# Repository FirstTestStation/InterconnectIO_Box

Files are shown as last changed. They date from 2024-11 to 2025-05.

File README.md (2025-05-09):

# FIRST STATION TEST InterconnectIO_BOX 500-1000-010

## Project Overview
This project involves the assembly of a custom **InterconnectIO_BOX** designed to be part of the **First TestStation** project ([FTS](https://FirstTestStation.github.io/FTS_Website/)). The primary goal of the InterconnectIO_BOX is to provide an interface between instruments and the Unit Under Test (U.U.T).

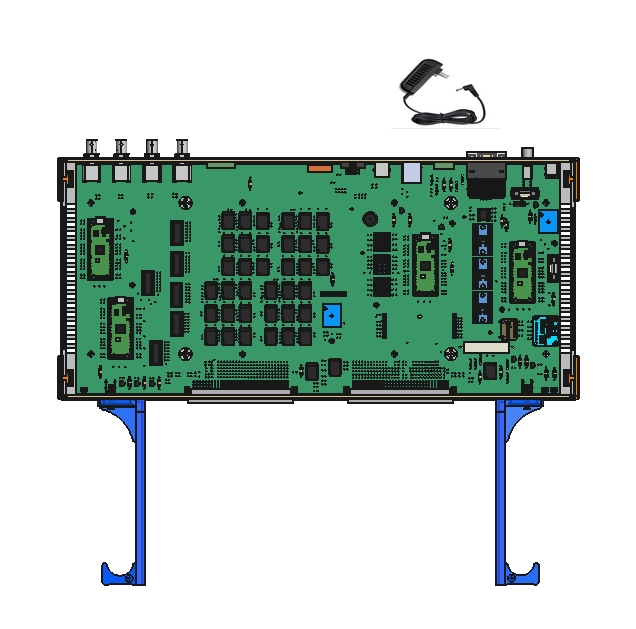
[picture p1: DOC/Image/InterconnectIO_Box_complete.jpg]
Box


### Design Tools
- [Freecad 0.20.2 ](https://www.freecad.org/) - Free software application used to design rail guides and assemble the box.
- [Inkscape 1.1.2 ](https://inkscape.org/) - Free software application used to design front and back panel.
- [LibreOffice](https://www.libreoffice.org/download/download-libreoffice/) - Free Software application used to create assembly instructions and the Bill of Materials (BOM).
- [PicPick](https://picpick.app/en/) - Free application to capture and document image.

### Features

- **Stand-alone Operation**: The box is capable of functioning independently, without requiring external instruments or additional equipment.
- **Rackmount Capability**: Designed to be easily mounted in a standard rack chassis, providing flexibility for different setups.
- **Cost-Effective**: Built using affordable, readily available components, ensuring low production costs.

## Assembly Instructions
   Follow the document [Assembly_Instructions](pdf/InterconnectIO_Box_Assembly_Instruction_520-1000.pdf) to complete the assembly of the board.

## Design Files
- [Left Card Guide stl File](Drawing/Left_guide_drawing_515-1000.stl) – STL file for the left rail, to be used with a 3D printer.
- [Right Card Guide stl File](Drawing/Right_guide_drawing_515-1010.stl) – STL file for the right rail, to be used with a 3D printer.
- [Front panel drawing](Drawing/Panel_Front_drawing_512-1000.svg) – SVG file for the front panel, to be used with a laser cutter.
- [Back panel drawing](Drawing/Panel_Back_drawing_512-1010.svg) – SVG file for the back panel, to be used with a laser cutter.
- [Bill of Materials(BOM)](pdf/BOM_InterconnectIO_Box_510-1000.pdf) – List of components required to complete the assembly.
- [Freecad Folder](Freecad/) – Freecad Original design files.

## Verification
The **InterconnectIO Box** is equipped with multiple built-in features designed to facilitate the comprehensive verification of hardware functionality. It supports **SCPI commands**, allowing for internal testing and diagnostics. The hardware has been engineered specifically to aid in the validation of board functionality, ensuring thorough and efficient testing.

For detailed testing procedures, please refer to the [Test_Instructions](pdf/InterconnectIO_Box_Test_Instruction_520-1010.pdf) document to complete the verification of the InterconnectIO Box.

> **Note:** Verification can also be performed using the OpenTAP TestPlan software available in the GitHub repository:  
> [OpenTAP Selftest Sequence](https://github.com/FirstTestStation/FTS_OpenTAP_Selftest_Sequence)

## License

This project is licensed under the terms of the [CERN Open Hardware License Version 2 - Weakly Reciprocal (CERN-OHL-W 2.0)](https://ohwr.org/cern_ohl_w_v2.txt).

See the [LICENSE](./LICENSE) file in this repository for more details.

---

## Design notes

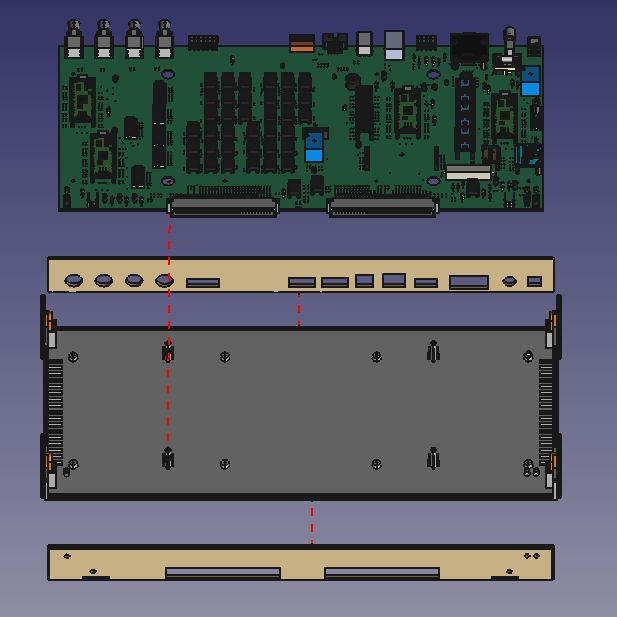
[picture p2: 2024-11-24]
DOC/Image/pcb_mount.jpg

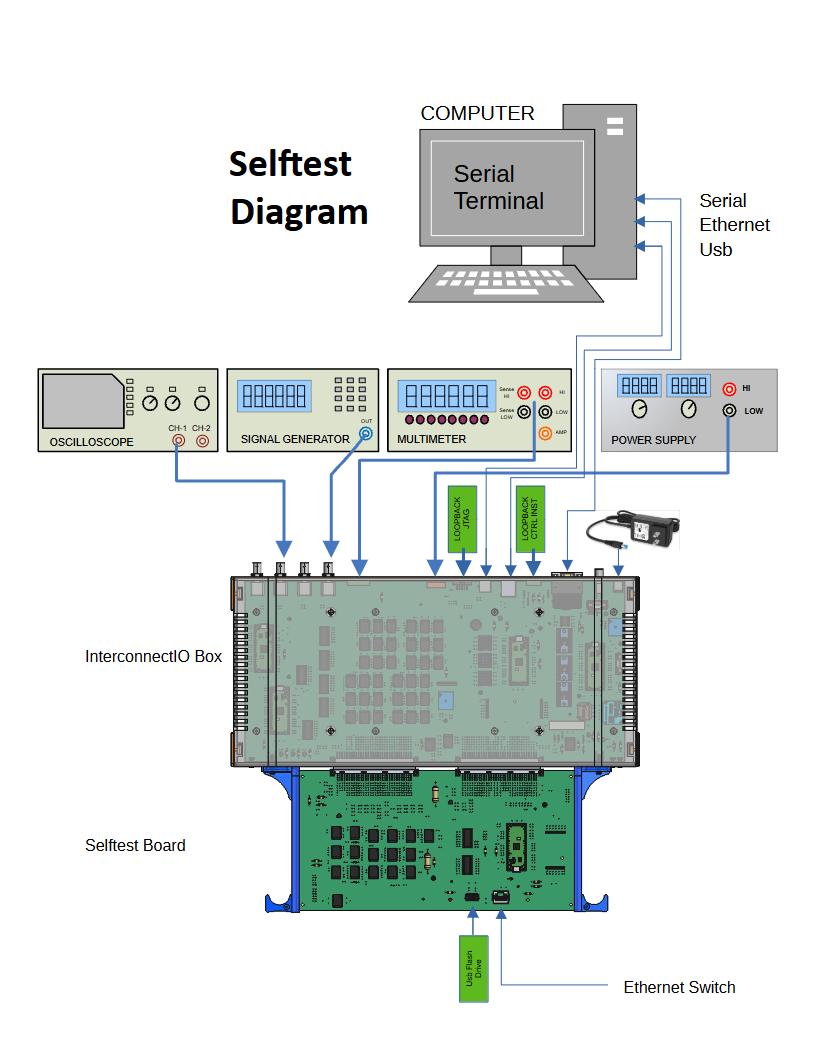
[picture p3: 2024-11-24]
DOC/Image/Selftest_diagram.jpg

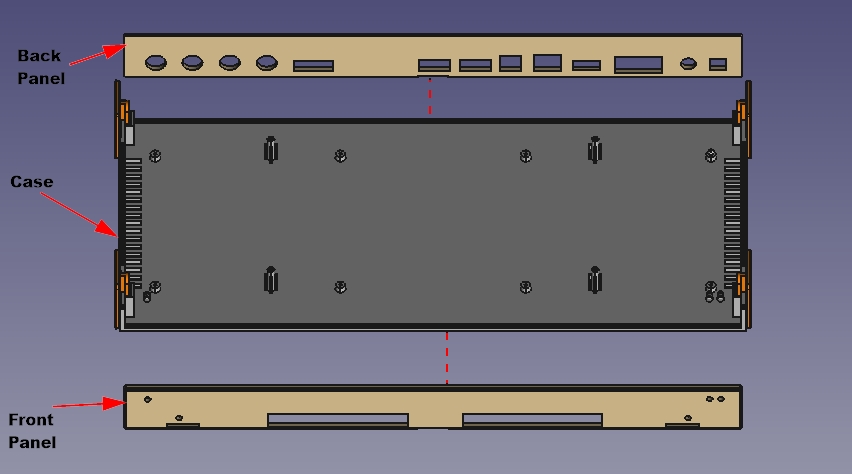
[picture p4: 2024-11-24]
DOC/Image/box_panel_doc.jpg

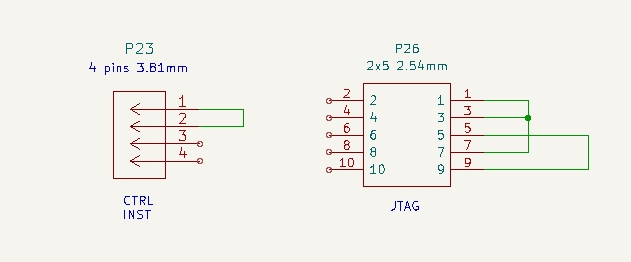
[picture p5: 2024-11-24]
DOC/Image/loopback_connector.jpg

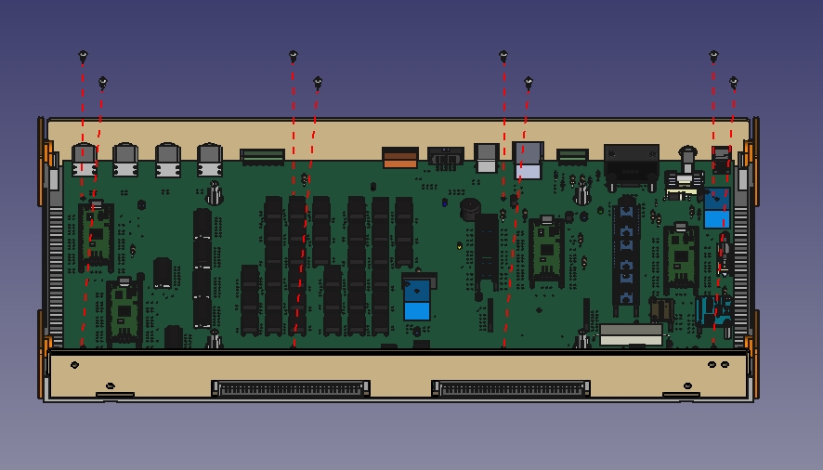
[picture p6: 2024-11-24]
DOC/Image/Board_screw.jpg

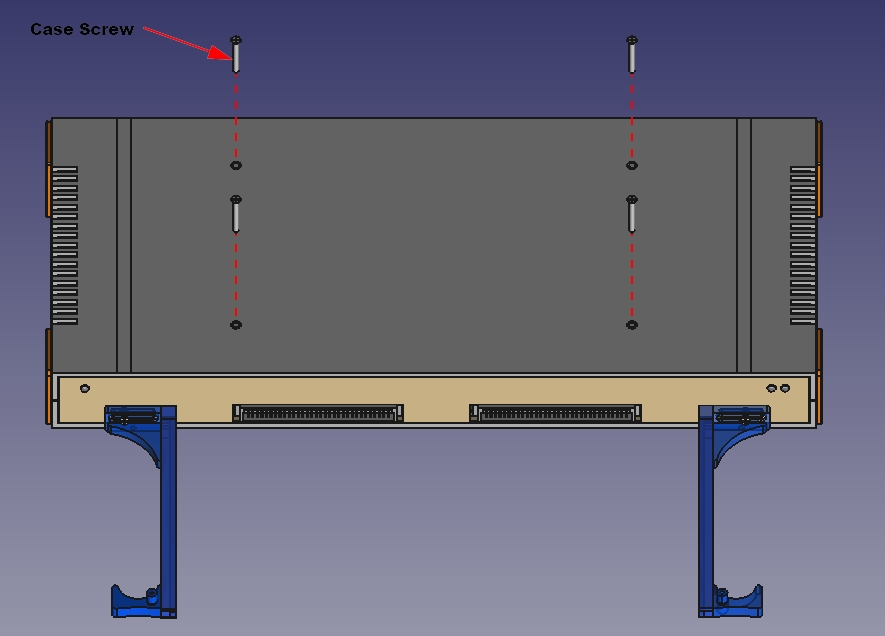
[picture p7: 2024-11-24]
DOC/Image/InterconnectIO_Box_complete doc.jpg

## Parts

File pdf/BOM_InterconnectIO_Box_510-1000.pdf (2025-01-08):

Sheet1

Page 1

# BOM InterconnectIO_Box

510-1000-010

Component for this board has been selected to be not expensive and available over the world. The quanty specified on the BOM are the required quanty and not the quanty received because most of the components sales by AliExpress

ITEM | Ref | Qty | Value | Component number | Component Link | Comment
1 | Case | 1 | PRM-46606 | 377-1962-ND | hps://www.digikey.ca/en/products/detail/bud-industries/PRM-14460/655427?s=N4IgTCBcDaIMwHYEFoCMBOAbGZA5AIiALoC%2BQA
2 | Led Lens | 3 | 3mm transparent | 10 pieces | hps://www.aliexpress.com/item/1005004808477552.html?spm=a2g0o.order_list.order_list_main.191.12331802Sgy38f
3 | Board Screw | 6 | M2.6 * 5mm | Black Carbon Steel | hps://www.aliexpress.com/item/1005003652695473.html?spm=a2g0o.cart.0.0.5d5038daUP4x&mp=1
4 | Rail screw | 2 | M3.*16mm | M3 25pcs/16mm | hps://www.aliexpress.com/item/1005002205244614.html?spm=a2g0o.cart.0.0.1ee738da6zFkTi&mp=1
5 | Power pack 5V 3A | 1 | 5V @3A | 3A/5V/US Plug | https://www.aliexpress.com/item/32986101102.html?spm=a2g0o.cart.0.0.754738dadsdtwz&mp=1
6 | Front Panel | 1 | 512-1000-010 | Panel_Front_drawing.svg | laser cut made on 0.125 thickness plywood wood. Wood dimension of 42.5 cm x 4.2cm
7 | Back Panel | 1 | 512-1010-010 | Panel_Back_drawing.svg | laser cut made on 0.125 thickness plywood wood. Wood dimension of 42.5 cm x 4.2cm
8 | Left guide rail | 1 | 515-1000-010 | Left_guide_drawing_515-1000.stl | 3d printed using blue PLA filament
9 | Right guide rail | 1 | 515-1010-010 | Right_guide_drawing_515-1010.stl | 3d printed using blue PLA filament
10 | InterconnectIO Board | 1 | 600-1000-011 | Assembled PCB

## MATING Connectors for reference (Oponnal)

1 | P23 | 1 | 4 pins 3.81mm | plug, 5PCS,4P,3.81mm | https://www.aliexpress.com/item/32880910367.html?spm=a2g0o.order_list.order_list_main.97.176818025xbVoN
2 | P20 | 1 | 6 pins 3.81mm | plug, 5PCS,6P,3.81mm | https://www.aliexpress.com/item/32880910367.html?spm=a2g0o.cart.0.0.255038daF8f4Ji&mp=1
3 | P17 | 1 | 4 pins,5.08mm | Right angle, 5Pairs,4P | https://www.aliexpress.com/item/1005001666625465.html?spm=a2g0o.cart.0.0.214838daHo7RzR&mp=1
4 | P26 | 1 | 2x5pins,2.54mm | 2x5p 10Pin | https://www.aliexpress.com/item/1005005367851508.html?spm=a2g0o.cart.0.0.2cf438dabYVYbN&mp=1
5 | P18,P19,P21,P22 | 4 | Bnc cable | BNC cable 50 ohm, 1 meter | https://www.aliexpress.com/item/1005005417715961.html?spm=a2g0o.cart.0.0.6cff38dawVV3kD&mp=1
6 | P25 | 1 | Usb cable | Type A to B Male | https://www.aliexpress.com/item/1005005507244620.html?spm=a2g0o.cart.0.0.32d438datJcCc8&mp=1
7 | P24 | 1 | Eth Cable | White Ethernet Cable/China/1m | https://www.aliexpress.com/item/33026678139.html?spm=a2g0o.cart.0.0.415138daTYDIeB&mp=1
8 | P1, P2, | 2 | 9001-12961C00A | 396-STR-F | hps://www.aliexpress.com/item/32808173331.html?spm=a2g0o.order_detail.order_detail_item.3.8a9af19cRF49dn

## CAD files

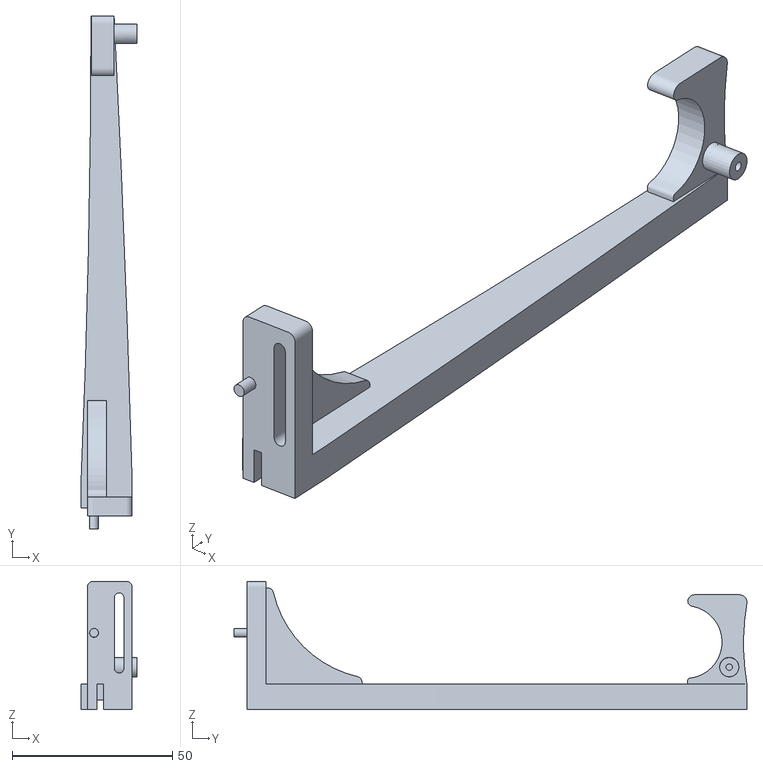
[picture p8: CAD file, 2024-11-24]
Drawing/Right_guide_drawing_515-1010.stl
17.5 x 160.0 x 40.0

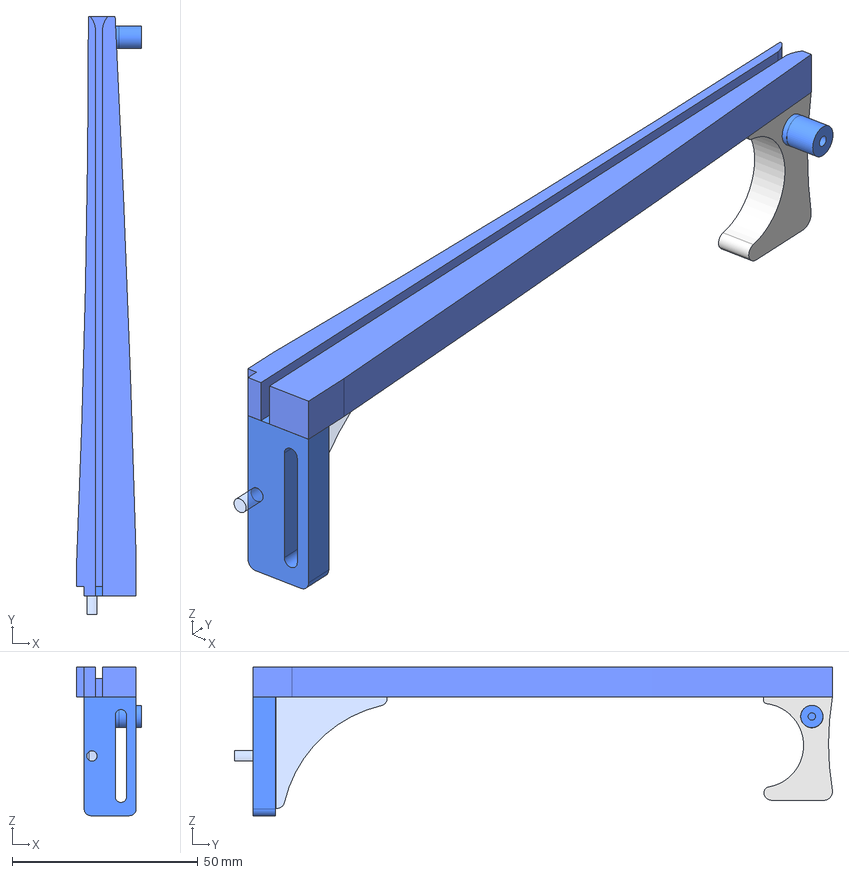
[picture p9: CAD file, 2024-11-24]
Freecad/Left_guide_drawing_515-1000.FCStd
17.4 x 161.0 x 40.0 mm
rail x 2
sideforce x 2
finger x 2
Cyl_Guide x 2
Base x 2

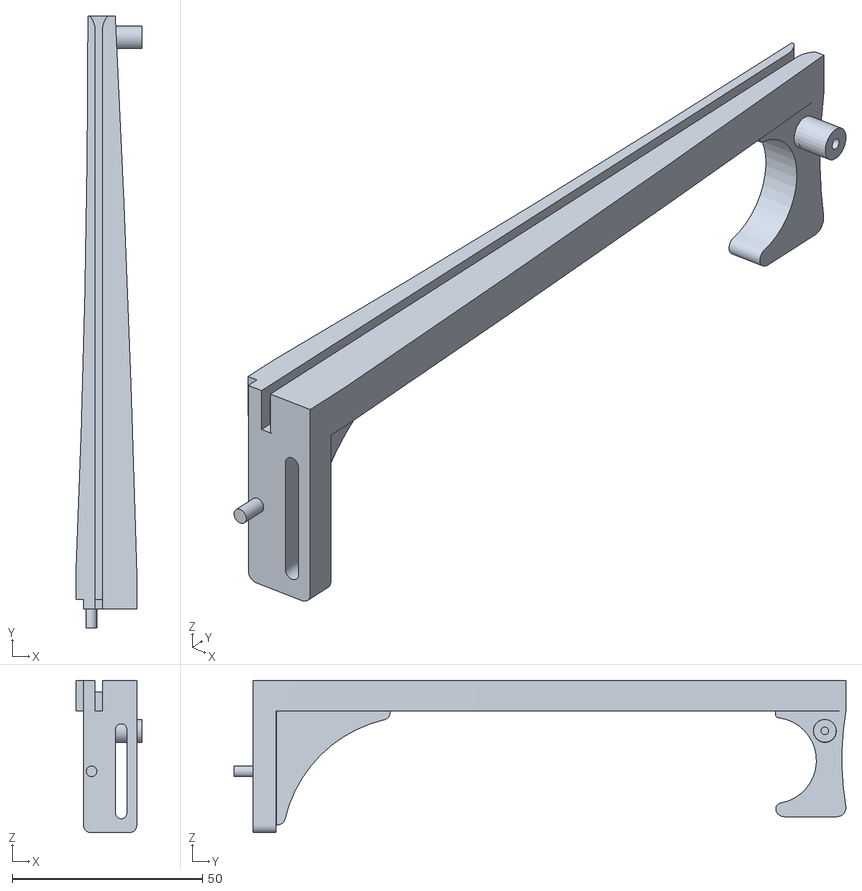
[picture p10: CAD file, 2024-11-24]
Drawing/Left_guide_drawing_515-1000.stl
17.4 x 161.0 x 40.0

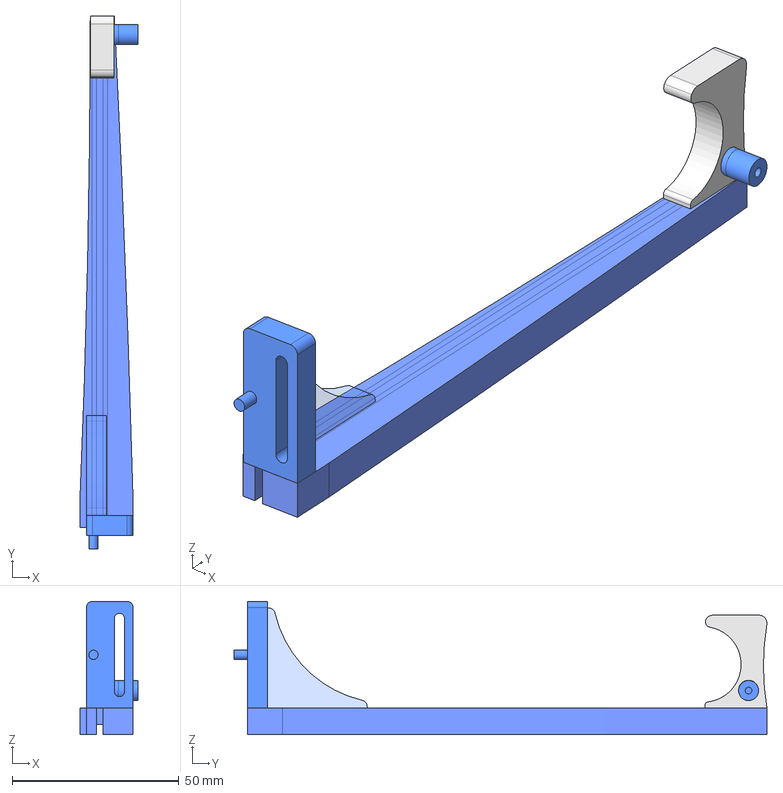
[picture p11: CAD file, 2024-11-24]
Freecad/Right_guide_drawing_515-1010.FCStd
17.5 x 160.0 x 40.0 mm
rail x 2
sideforce x 2
finger x 2
Base x 2

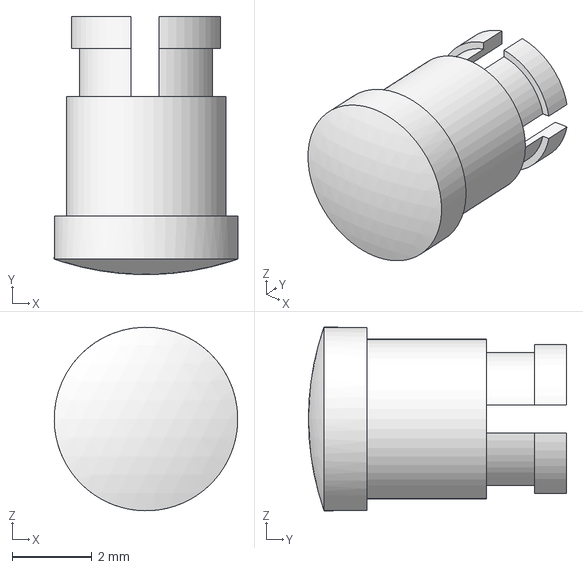
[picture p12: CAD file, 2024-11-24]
Freecad/led_lens.FCStd
4.60 x 6.47 x 4.60 mm

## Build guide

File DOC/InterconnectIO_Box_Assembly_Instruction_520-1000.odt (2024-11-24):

INTERCONNECTIO_BOX ASSEMBLY INSTRUCTIONS

520-1000-010

This document provides detailed instructions on how to assemble the InterconnectIO_Box.

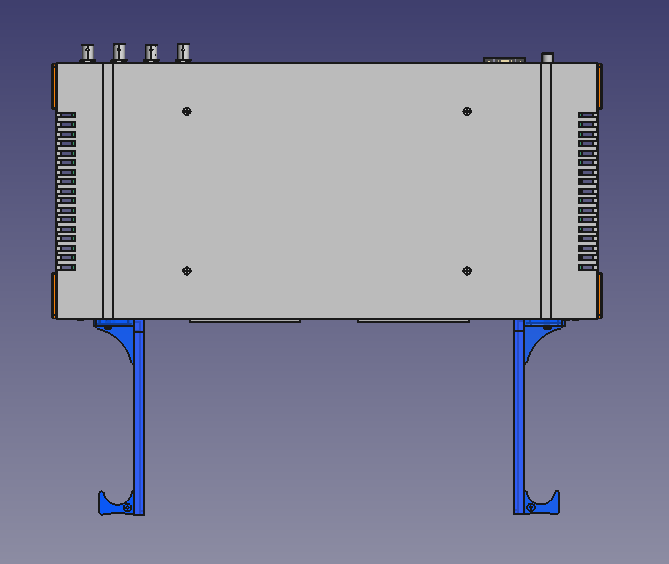
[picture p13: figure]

The case was selected based on its cost and its ability to be mounted in a rackmount cabinet. The front and back panels are custom-made for this project and were designed to be laser-cut. The board guide rails were designed to attach to the front panel, with a finger loop added at the top of the guide rails to assist with the insertion and extraction of the interface board.

### PREPARATION

Some components are specific to the project and need to be custom-cut or 3D-printed before use. For this project, FabLabs (Fabrication Laboratories) were utilized for 3D printing the parts and laser-cutting the panels.

1. Panels

The front and back panels have been laser-cut from 3.175mm plywood. The panel edges must have a maximum thickness of 2.54mm to fit into the case slots designed for the panels.

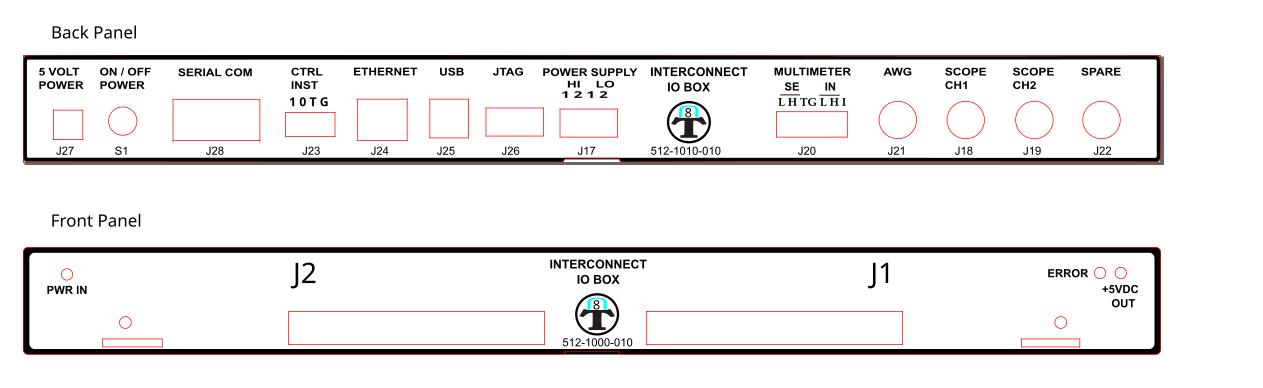
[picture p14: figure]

While the panels can be made from other materials (such as aluminum, plastic, etc.), plywood was chosen for this prototype as the most economical option.

2. Guide rail

The guide rails are essential for aligning the interface board with the connectors on the InterconnectIO_Box. They have been specially designed to help the operator insert and remove the interface board without applying excessive force.

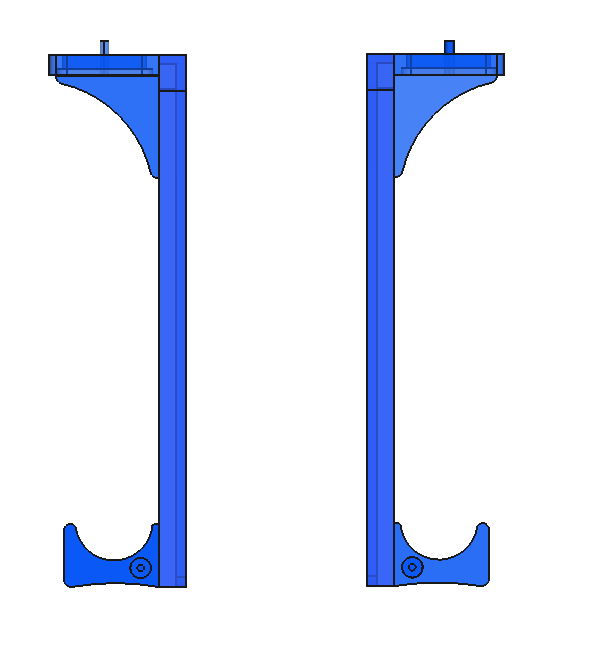
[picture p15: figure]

A screw slot has been added to the base of the rails to allow for adjustment according to the size of the interface board. The guide rails were 3D-printed using blue PLA (Polylactic Acid) filament on an Ultimaker S3.

### ASSEMBLY INSTRUCTIONS

Follow these steps to successfully assemble the Box:

#### Preparation

- Ensure you have the required components and tools (Philips screwdriver).
- Review the Bill of Materials (BOM) to ensure all parts are available.

### Step-by-Step Instructions

1. Front and Back panel: Insert the custom front and back panels into the slots on the bottom of the case.


2. Insert PCB: Install the InterconnectIO Board into the case, aligning the connectors with the front and back panels. Secure the board using screws.

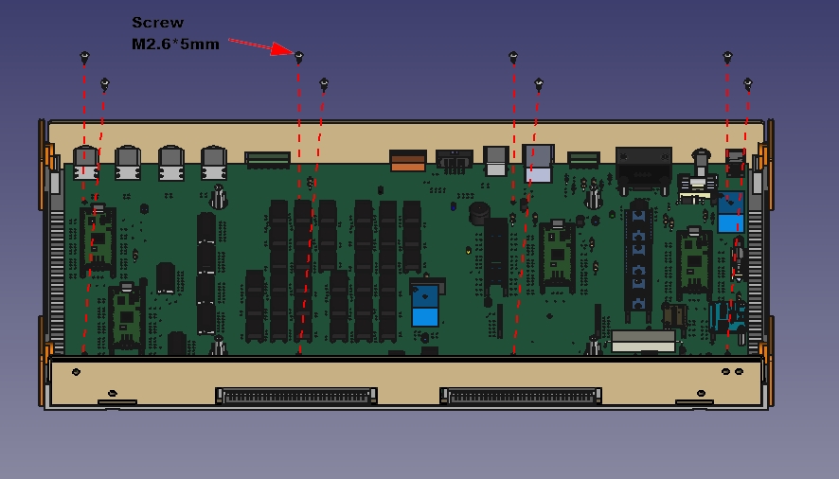
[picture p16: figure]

3. Insert Led Lens: Insert the LED lens into the front panel, then push the LED into the holder.
4. Install Guide rails: Install the guide rails and secure them with screws. Slide the interface board into the front panel to connect it with the connectors. Adjust the guide rails to ensure the interface board fits properly within the rails, then tighten the guide rail screws. Verify that the interface board slides in and out smoothly.

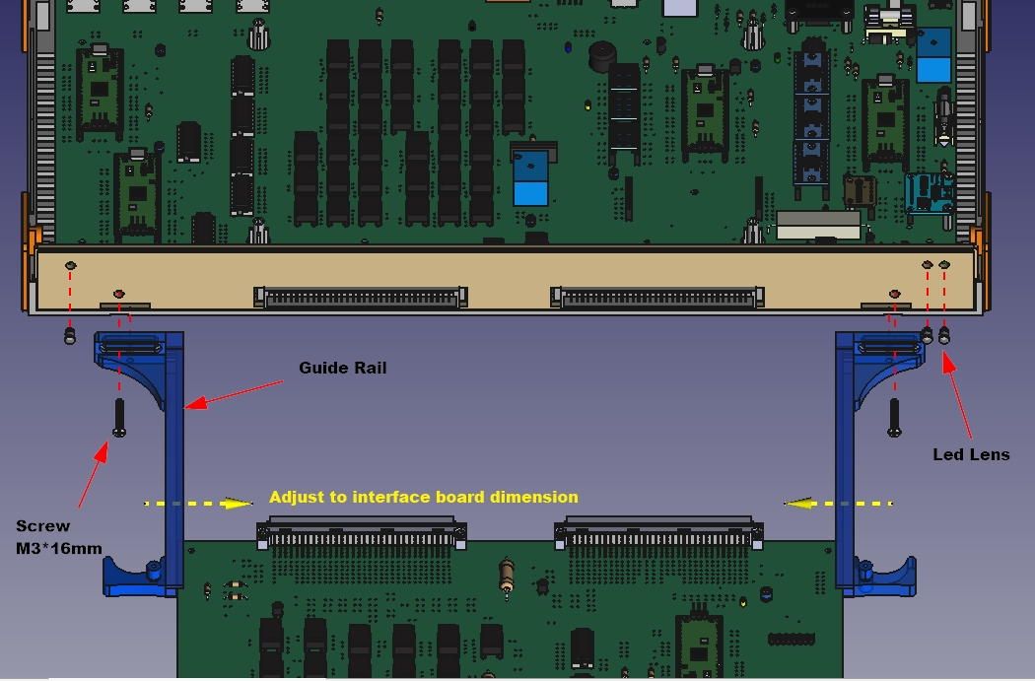
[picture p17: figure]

5. Install top case cover: Finally, install the top case cover and secure it with the provided screws.


### TESTING

1. Power On:
  - Connect 5V power pack to the Box
  - Press Power button
  - The green led marked PWR IN is ON (5V indicator).
  - The 4 Pico controller green led is flashing slowly (top cover removed)
2. Test Serial Communication: Connect the computer's serial port to the InterconnectIO Box serial port using protocol **N81** and set the baud rate to **115200**. Using a terminal program on the computer, send the SCPI command `*IDN?` and verify if the box responds correctly with an identification message.

Box testing is complete. Comprehensive testing of the board will require additional hardware and will be included in the First Test Station documentation.

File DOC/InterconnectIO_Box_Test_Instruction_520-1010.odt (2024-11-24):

INTERCONNECTIO_BOX TEST INSTRUCTIONS

520-1010-010

This document provides detailed instructions for testing the InterconnectIO_Box to validate its functionality.

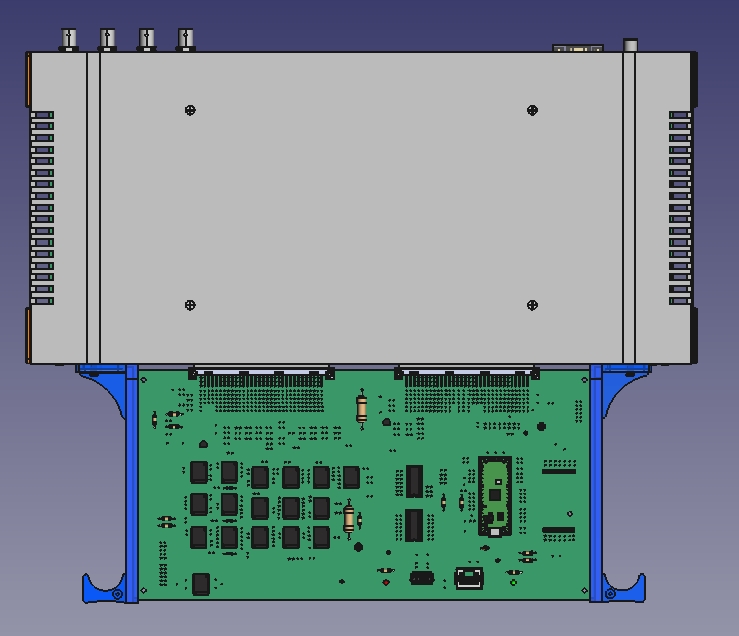
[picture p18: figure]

Validation of the InterconnectIO Box using the self-test board was intended to be the first program written with OpenTAP software. However, the designer chose to delay the development of the high-level software, instead incorporating a comprehensive built-in self-test within the Master software to verify both hardware and software functionality."

The built-in selftest can be executed using simple SCPI commands but requires the selftest board to be connected to the InterconnectIO_Box. Additional hardware, such as a loopback connector, and instruments can be added to the InterconnectIO_Box to increase test coverage."

Features

- Built-In SelfTest: A complete self-test can be initiated using the simple SCPI command: SYST:TEST.
- Debug Messages: Detailed messages are sent to the debug serial port (Pico USB port) for troubleshooting.
- Loopback Connectors: Some functions of the InterconnectIO_Box can be validated using loopback connectors.
- Instrument Validation: External instrument functionality is validated manually. Step-by-step instructions are provided to the operator to complete the self-test sequence. Programmable instruments are not required for the built-in selftest.

### Hardware

HARDWARE

This section defines the materials required to perform the complete validation test of the InterconnectIO_Box.

The built-in self-test is designed to support different levels of testing. The basic level requires no additional hardware aside from the self-test board, while more advanced levels will require external instruments or loopback connectors.

By dividing the complete test of the InterconnectIO Box into sections, the testing sequence becomes more comprehensible, and debugging is made easier.


1. Level 1 Test: Electronics Validation
  The level 1 test the electronic on the board following the defined test strategy. Recommended to run for assembled board, the test is automatic and follow the test strategies.
  Material: Selftest Board 600-1010-xxx

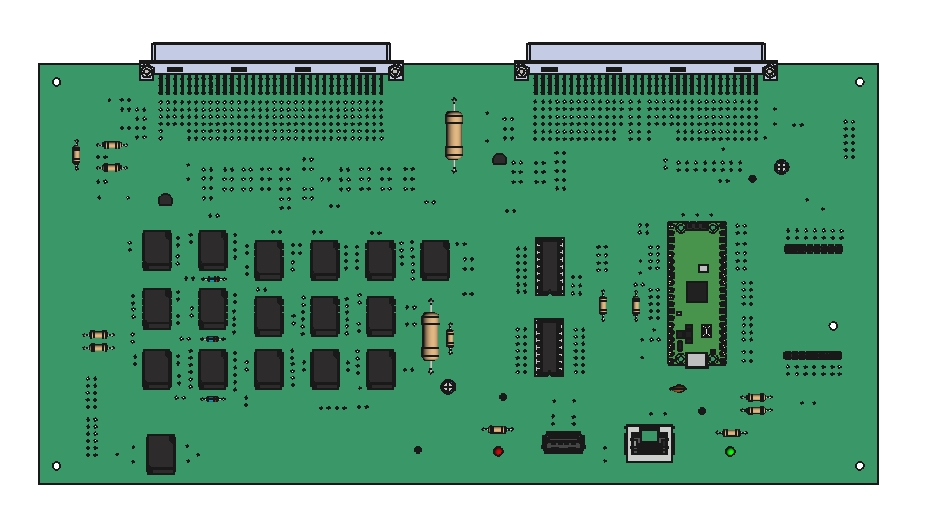
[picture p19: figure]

2. Level 2 Test: Loopback Connectors Addition
  Level 2 adds loopback connectors (see electrical diagram below) to the test, allowing the validation of the functionality of the CTRL_INST and JTAG connectors. For the JTAG connector, the test only verifies the wiring traces and does not follow the full JTAG protocol.


Materials:

- 4 pins 3.81mm female connector with wire between P23.1 and P23.2
- 10 pins (2x5 pins 2.54mm) female connector with wires between P26.1, P26.3 and P26.7. Add second wire between P26.5 and P26.7
  - Selftest Board 600-1010-xxx

When wiring completed, P23 and P26 will be connected to J23 and J26 on the back panel of the InterconnectIO box

3. Level 3 Test: External Instrument Validation
  Validate the test of the electronics wired to the external instruments. During normal usage of the First Station Test (FTS), the instruments are controlled by the OpenTap software, and the test is performed automatically without any intervention. However, during a built-in self-test, the instruments are manually controlled, and connections can be moved from one point to another to reduce the number of instruments required to complete the test.

Materials:

- Digital Multimeter with Volt Amp Ohm
- 2-channel Oscilloscopes
- Sinus and Triangle Signal generators
- Variable Power Supply (0-12V @ 500 mA)
- Formatted USB Flash Drive
- Ethernet Network
4. Serial Interface
  The communication with the InterconnectIO_Box uses a standard serial port without handshaking. A computer running Windows or Linux can be used.

Materials:

  - Serial cable with DB9 Female or USB to Serial adapter
  - Free Serial Terminal application (Putty on PC or CuteCom on Linux)
  - USB Type-A to Micro-USB cable to use with the serial console

The serial protocol used is N81 (No parity, 8 bits, and 1 stop bit), with a default Baudrate of 115200. Each Raspberry Pi Pico controller located on the InterconnectIO_Box is programmed to use the USB connector for serial communication using the N81 protocol and a Baudrate of 115200. The usage of this interface is similar to a serial console and can be used to monitor commands received by each Pico.

### VALIDATION

This section provides the procedure to follow to perform the built-in self-test. The procedure assumes that the initial test of the InterconnectIO_Box and the Selftest Board has been successfully completed.

### Step 1: Serial Communication

1. Connect the serial cable between the computer and the InterconnectIO_Box.
2. Open a terminal application and configure it with the following settings:
  - Protocol: N81 (No parity, 8 data bits, 1 stop bit)
  - Baud rate: 115200
3. Turn on the InterconnectIO Box.
4. Verify in the terminal that the display shows:
  FTS>

If message not displayed, open the cover of InterconnectIO_Box and connect USB cable to the Master Pico. Setup second terminal to N81 @ 115200 and turn ON the InterconnectIO_Box. Verify in the terminal that the display shows (could take 10 secs):

The actual baudrate used to serial communication is displayed. The Baudrate need to be rounded, in this case, he will be rounded to 115200.

Heartbeat Master,Baudrate: 115207, version 1.0

### Step 2: Preliminary Check

1. Type in Terminal the command *IDN?
2. Verify in the terminal that the display shows:
  FTS> *IDN? FirstTestStation,InterconnectIO,2022A,1.0

if no answer received, verify on the master serial console if the message has been received (see image below).

FirstTestStation,InterconnectIO,2022A,1.0

SCPI Command: *IDN?

### Step 3: Built-in Selftest Execution

1. Type in Terminal the command SYST:TEST
2. Verify in the terminal that the display shows:

SYST:TEST

Internal Test Sequences

1- Selftest using only selftest board, no check of Onewire

2- Selftest run only if selftest board is installed, Onewire validation

3- Selftest using selftest board and loopback connector

4- Selftest of instruments in manual mode using selftest board

5- Test of SCPI command,selftest board is required

0- Exit test sequence

Enter test number to execute and press enter:

3. Type in Terminal the number 4 (Test of SCPI Command)
4. Verify in the terminal that the display shows:

TEST COMMAND RESULTS:
NbTotal: 137, NbGood: 137, NbBad: 0, NbError: 0
TEST COMMAND COMPLETED

5. Type in Terminal the number 1 (Selftest only)
6. Verify in the terminal that the display shows:

SELFTEST RESULTS:

NbTotal: 211, NbGood: 211, NbBad: 0, NbError: 0

SELFTEST COMPLETED

7. Type in Terminal the number 3 (Selftest + Loopback)
8. Verify in the terminal that the display shows:
9. Type in Terminal the number 4 (Selftest of Instruments) SELF TEST RESULTS: NbTotal: 231, NbGood: 231, NbBad: 0, NbError: 0 SELFTEST COMPLETED
10. Follow step by step instructions on terminal to complete the test.
11. Verify in the terminal that the display shows:
12. Type in Terminal the number 0 (Exit Built-in Selftest) Manual Instruments Test Connect DMM to Sense pins (+:J20-5 & -:J20-6) Set DMM to be able to read 10 ohms resistors

### Debugging Steps for Selftest Failure:

1. Repeat the Test:
  - Run the selftest again to ensure that the failure is not intermittent or caused by a temporary issue. This helps confirm whether the issue is consistent or was a one-time error.
2. Verify Fail Test Functionality:
  - Check the Validation Table Document to confirm the expected behavior for each test function. Ensure that all test criteria are properly defined and that the failure aligns with the documented conditions.
3. Analyze Results on the Serial Console:
  - Carefully examine the output on the serial console. Look for any error codes, messages, or patterns that might indicate the root cause of the failure. These could point to specific parts of the system, such as communication errors or hardware issues.
4. Send Commands Manually:
  - To further isolate the problem, send the relevant commands manually from the terminal to reproduce the failure. This will allow you to directly observe the system's behavior in response to the commands and check if the failure can be replicated.
5. Perform Correction and Repeat the Test:
  - Once the issue has been identified, apply the necessary corrections (e.g., fix wiring, adjust configuration, replace faulty components). After the correction, rerun the selftest to ensure that the problem is resolved and the system is functioning as expected.

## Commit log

2024-11-24 First deposit
    [BOM_Hardware_Assembly_InterconnectIO_Box_500-1000.ods, Left_guide_drawing_515-1000.FCStd, Left_guide_drawing_515-1000.stl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]
2025-01-08 add partnumber to name
    [BOM_Hardware_Assembly_InterconnectIO_Box_500-1000.ods, BOM_InterconnectIO_Box_510-1000.ods]
